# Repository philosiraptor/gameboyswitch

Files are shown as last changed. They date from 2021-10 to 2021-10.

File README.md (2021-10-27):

# gameboyswitch
I added joycons to a gameboy advanced sp
if you actually build this let me know.
software component is written in java (SIGH I KNOW)
you will need to get java up and running on a pi zero, its a pain in the butt. 
oh and for some reason the joycons will disconnect if wifi on the pi is enabled,
youll want to run the pi headless over usb (google it)

also you can just order from pcbway to get the board
https://www.pcbway.com/project/shareproject/ground_boi_signal.html

heres a huge iso you can download, burn it with rufus/balena/ idk a tuna sandwich
https://drive.google.com/file/d/150eEt6jt2sRTaDK3TDJbanNfYEL_4Ezm/view?usp=sharing

these instructions are intentionally vauge because you should not build this.

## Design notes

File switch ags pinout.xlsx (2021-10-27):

RPI TO AGS PINOUT
RPI | AGS HEADER | GPIO
2 | 15 | 3.3VDC
9 | 1 | GND
11 | 13 | GPIO 0
13 | 12 | GPIO 2
15 | 11 | GPIO 3
16 | 10 | GPIO 4
18 | 9 | GPIO 5
22 | 8 | GPIO 6
29 | 5 | GPIO 21
31 | 6 | GPIO 22
32 | 3 | GPIO 26
33 | 2 | GPIO 23
36 | 7 | GPIO 27
37 | 4 | GPIO 25
FINAL WIRING
RPI-AGS BOARD | GAMEBOY MOTHERBOARD
1 | GND to switch, other sw wire to charge controller
2 | TP6
3 | TP7
4 | TP5
5 | TP4
6 | TP2
7 | TP9
8 | TP0
9 | TP1
10 | TP3
11 | TP8
12
13
14
15 | 5v power to charge controller and R9

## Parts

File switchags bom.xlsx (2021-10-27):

part | qty
2n2222 transistor | 12
film resistor 270 Ω | 12
pcb | 1
raspberry pi zero w | 1
pin headers 40 pin male | 1
30 awg wire 1 roll | 1
case | 1
switch rails | 2
usb c charger circuit | 1
toggle switch | 1

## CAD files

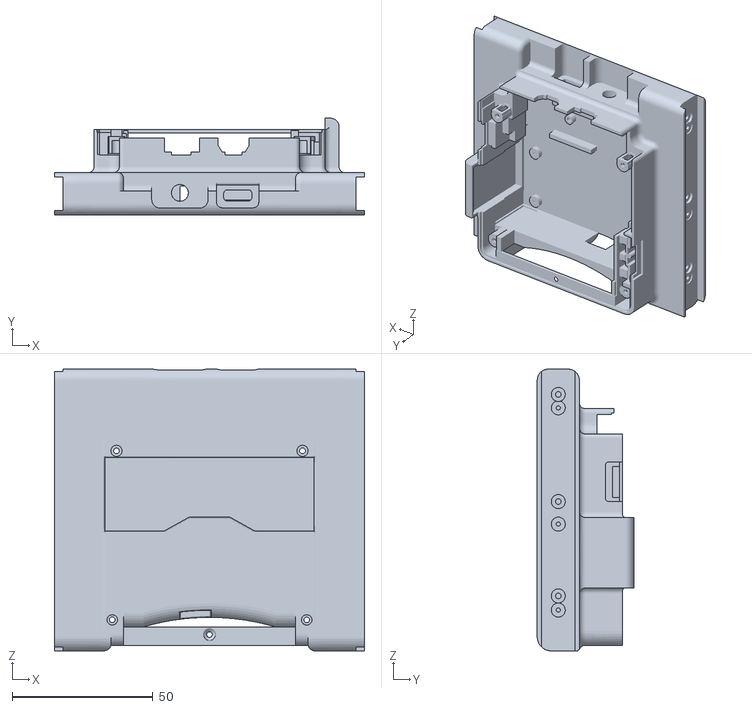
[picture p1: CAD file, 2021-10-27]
shell.stl
110.0 x 34.3 x 100.0

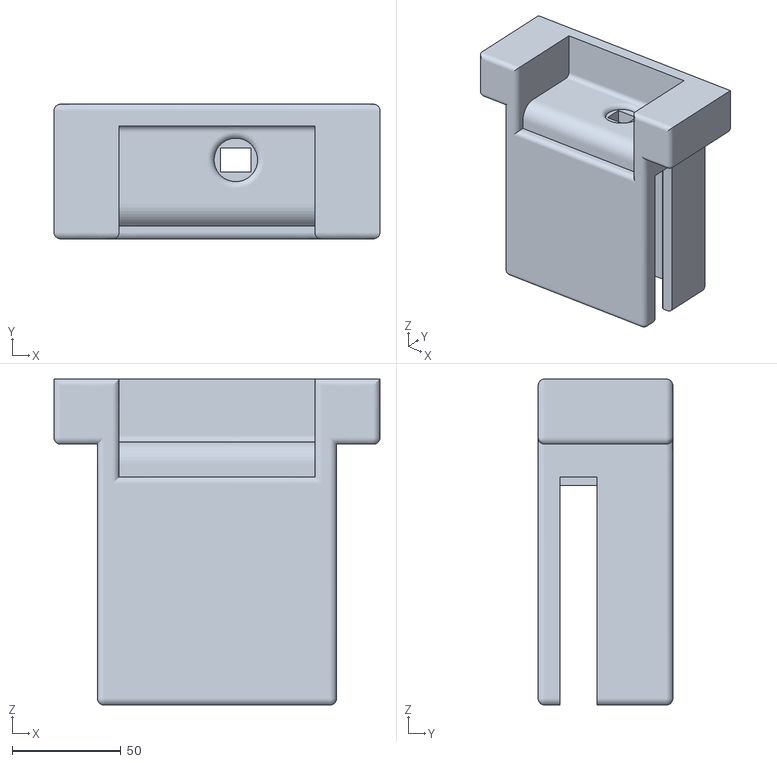
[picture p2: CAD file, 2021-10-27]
dock.stl
150.0 x 62.0 x 150.0

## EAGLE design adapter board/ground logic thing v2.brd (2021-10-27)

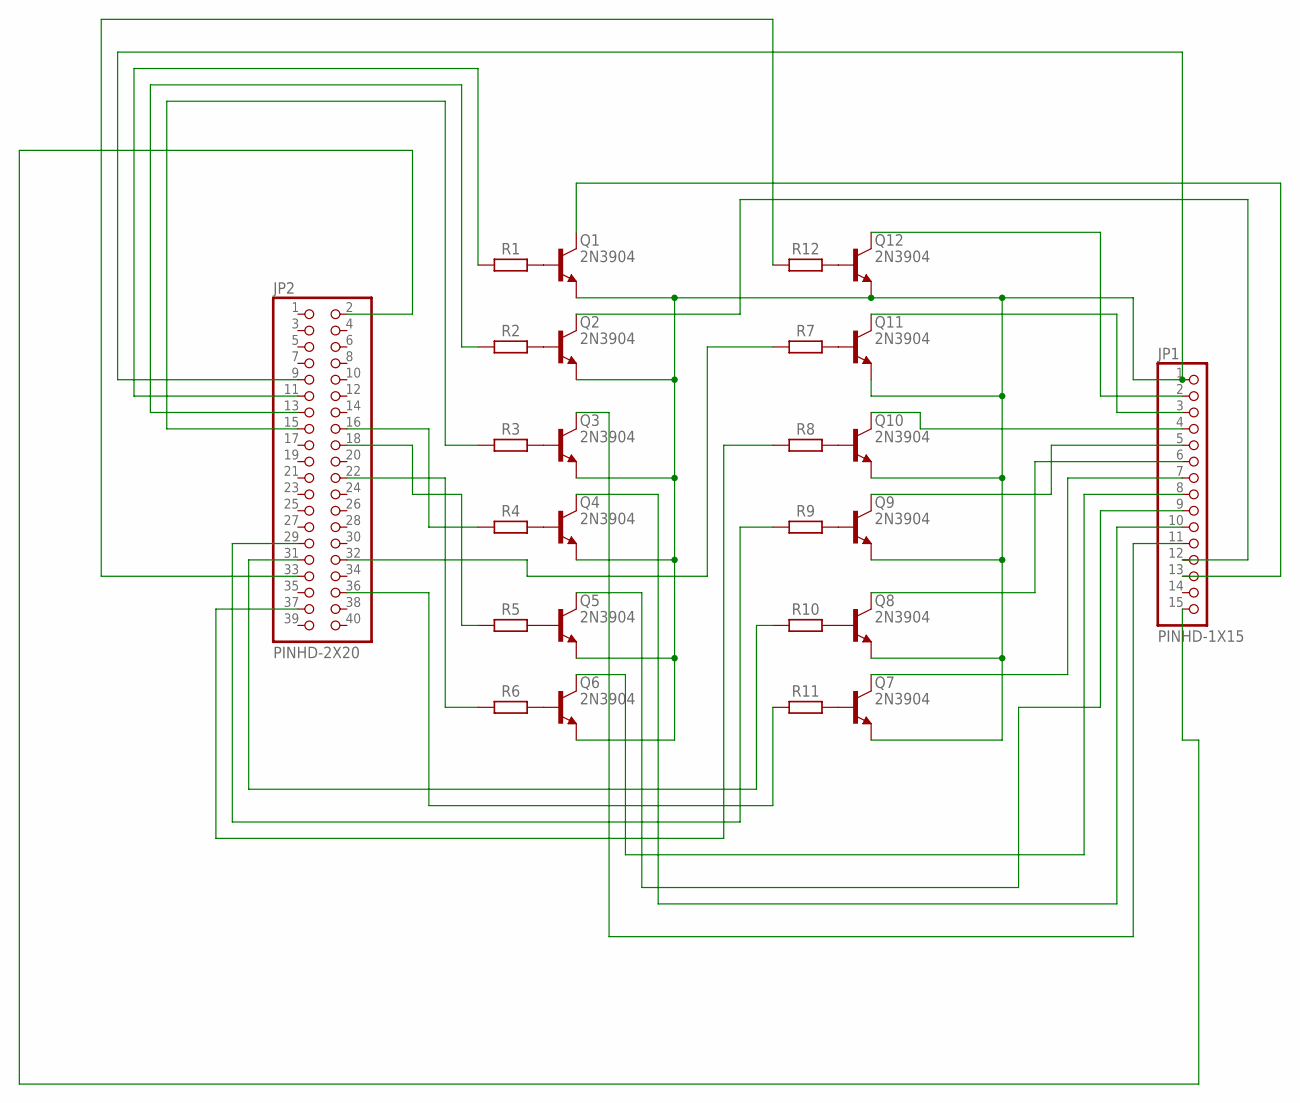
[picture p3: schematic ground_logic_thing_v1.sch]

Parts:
JP1: PINHD-1X15; 1X15
JP2: PINHD-2X20; 2X20
Q1, Q2, Q3, Q4, Q5, Q6, Q7, Q8, Q9, Q10, Q11, Q12: 2N3904; TO92
R1, R2, R3, R4, R5, R6, R7, R8, R9, R10, R11, R12: R_AXIAL-7.2MM-PITCH; RESAD724W46L381D178B

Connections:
unnamed: Q1.2 (B), R1.2
unnamed: Q2.2 (B), R2.2
unnamed: Q3.2 (B), R3.2
unnamed: Q4.2 (B), R4.2
unnamed: Q5.2 (B), R5.2
unnamed: Q6.2 (B), R6.2
unnamed: Q11.2 (B), R7.2
unnamed: Q10.2 (B), R8.2
unnamed: Q9.2 (B), R9.2
unnamed: Q8.2 (B), R10.2
unnamed: Q7.2 (B), R11.2
unnamed: Q12.2 (B), R12.2
unnamed: JP1.1, JP2.9, Q1.1 (E), Q2.1 (E), Q3.1 (E), Q4.1 (E), Q5.1 (E), Q6.1 (E), Q7.1 (E), Q8.1 (E), Q9.1 (E), Q10.1 (E), Q11.1 (E), Q12.1 (E)
unnamed: JP2.11, R1.1
unnamed: JP2.13, R2.1
unnamed: JP2.15, R3.1
unnamed: JP2.16, R4.1
unnamed: JP2.18, R5.1
unnamed: JP2.22, R6.1
unnamed: JP2.36, R11.1
unnamed: JP2.31, R10.1
unnamed: JP2.29, R9.1
unnamed: JP2.37, R8.1
unnamed: JP2.32, R7.1
unnamed: JP2.33, R12.1
unnamed: JP1.15, JP2.2
unnamed: JP1.2, Q12.3 (C)
unnamed: JP1.3, Q11.3 (C)
unnamed: JP1.4, Q10.3 (C)
unnamed: JP1.5, Q9.3 (C)
unnamed: JP1.6, Q8.3 (C)
unnamed: JP1.7, Q7.3 (C)
unnamed: JP1.8, Q6.3 (C)
unnamed: JP1.9, Q5.3 (C)
unnamed: JP1.10, Q4.3 (C)
unnamed: JP1.11, Q3.3 (C)
unnamed: JP1.12, Q2.3 (C)
unnamed: JP1.13, Q1.3 (C)

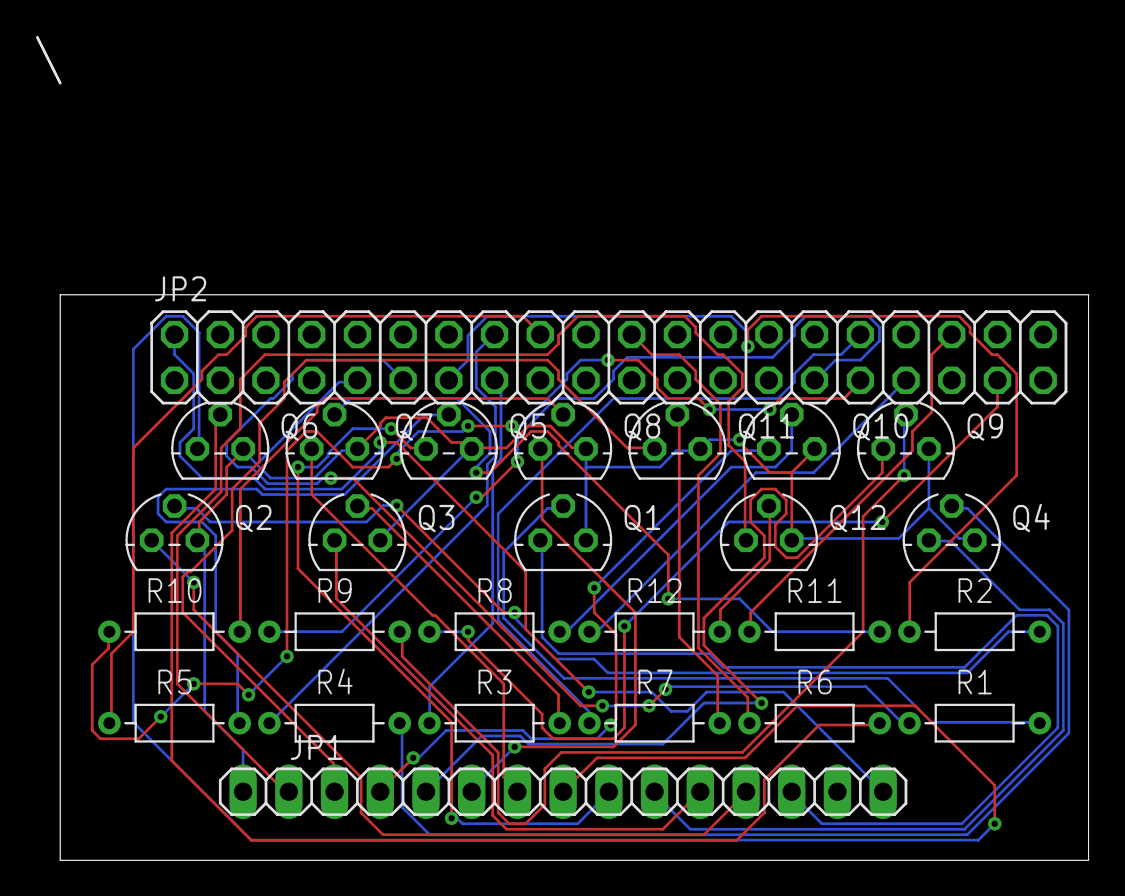
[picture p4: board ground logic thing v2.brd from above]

Board: 2 copper layers, 57.1 x 31.4 mm, 26 parts (0 on the bottom side), 38 nets.

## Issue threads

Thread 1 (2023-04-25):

add ability to do this over a port rather than soldering directly

tomoakley, 2023-04-25:
Hi, I came across this project and I think it's great! I haven't built it yet as I don't have a GBA SP, but I may get one soon to try and do it.

However I do have a modded Gameboy Advance. I have an idea for something that may or may not be possible; I'm not an electronics expert (I can do some soldering and stuff but PCB design etc are a bit too far currently, also I'm a software engineer so I somewhat understand the code).

What I envisage is a normal GBA (or SP) with the HDMI-out mod. Your custom PCB and Raspberry Pi could then be connected over some sort of port (USB-C? GBA Link connector?). Then you could play a game on the GBA (e.g while on commute) without any of the extra bulk from the PCB/rPi, get home, plug the HDMI in, and plug this new connector in which would allow the JoyCons to be connected. This could then be turned into a dock or something a la the Switch.

Is this possible? I'm unsure how the signals from the GBA buttons would reach the PCB/rPi over a cable though. That's where I need some help. Presumbably the PCB would need a port connection on; I'd really like to learn about PCB design a bit more so perhaps this might be a good opportunity. But maybe it's not possible at all! I'm not sure. Thanks.

philosiraptor, 2023-05-07:
this is absolutely possible, anything is if you define the specification for it! this would be a buttload of cad work but other than that mighty boulder to lift, your pretty much there.

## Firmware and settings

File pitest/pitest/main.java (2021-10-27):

//this project relies heavily on the work by the fine folks who made Pi4J possible
//as well as github user wheerdam's project https://github.com/wheerdam/linuxjoy
//im sorry, this probably isnt how to attribute but there it is 
//excuse my horrible cludged together code im just a lowly github copy paster 
// sn

package pitest;

import com.pi4j.io.gpio.GpioController;
import com.pi4j.io.gpio.GpioFactory;
import com.pi4j.io.gpio.GpioPin;
import com.pi4j.io.gpio.GpioPinDigitalInput;
import com.pi4j.io.gpio.GpioPinDigitalOutput;
import com.pi4j.io.gpio.PinDirection;
import com.pi4j.io.gpio.PinMode;
import com.pi4j.io.gpio.PinPullResistance;
import com.pi4j.io.gpio.PinState;
import com.pi4j.io.gpio.RaspiPin;
import com.pi4j.io.gpio.trigger.GpioCallbackTrigger;
import com.pi4j.io.gpio.trigger.GpioPulseStateTrigger;
import com.pi4j.io.gpio.trigger.GpioSetStateTrigger;
import com.pi4j.io.gpio.trigger.GpioSyncStateTrigger;
import com.pi4j.io.gpio.event.GpioPinListener;
import com.pi4j.io.gpio.event.GpioPinDigitalStateChangeEvent;
import com.pi4j.io.gpio.event.GpioPinEvent;
import com.pi4j.io.gpio.event.GpioPinListenerDigital;
import com.pi4j.io.gpio.event.PinEventType;
import java.util.concurrent.TimeUnit;
import org.bbi.linuxjoy.*;



public class main {
	

	public static void main(String[] args) {
		// TODO Auto-generated method stub
System.out.println("IM ALIVE");

// test for joystick
JoyFactory.enumerate();

LinuxJoystick j = JoyFactory.get(0);
LinuxJoystick k = JoyFactory.get(1);
//joystick button assignments
// left as follows:
// up = 2
// dn = 1
// L = 0
// R = 3
// sel = 8
//ltrig = 15
// right as follows:
// a = 0
// b = 2
// start = 9
// rtrig  = 15




if(j != null) {
	System.out.println("found joystick");
	j.startPollingThread(5); // sleep for 5 ms between polls
	j.setCallback(new EventCallbackHandlerleft());
}
if(k != null) {
	System.out.println("found other joystick");
	k.startPollingThread(5); // sleep for 5 ms between polls
	k.setCallback(new EventCallbackHandlerright());
}



//create gpio controller instance


do {
System.out.println("blink loop");
 
try {
	TimeUnit.SECONDS.sleep(1);
} catch (InterruptedException e) {
	// TODO Auto-generated catch block
	e.printStackTrace();
}

}while(true);

	}

}

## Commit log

2021-10-27 initial
    this is the app that runs on the raspberry pi
2021-10-27 additional init
    all the other stuff
    [dock.stl, ground logic thing v2.brd, ground_logic_thing_v1.sch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]
